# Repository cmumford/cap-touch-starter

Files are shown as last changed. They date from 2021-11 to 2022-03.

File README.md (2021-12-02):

# Introduction

This is a simple hardware/software starter project containing an
MCU (ESP32), and a capacitive touch screen. Nothing fancy, just
something to fork when starting a new project that needs these capabilities.

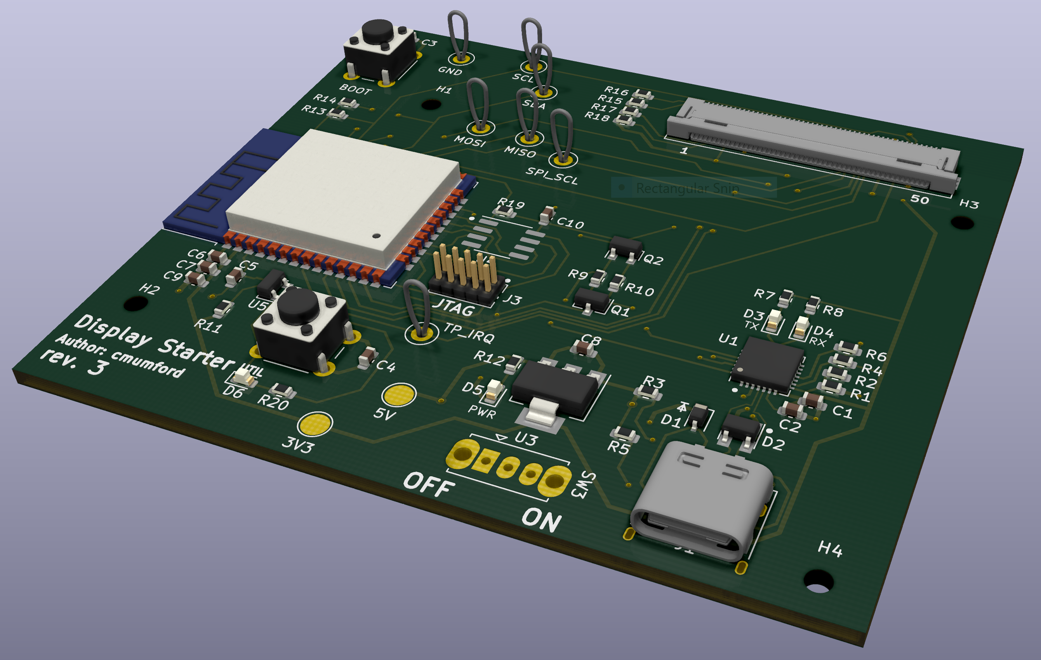
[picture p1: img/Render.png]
Board render


# Main Components

* ESP32-WROVER-E ([Datasheet](https://www.espressif.com/sites/default/files/documentation/esp32-wrover_datasheet_en.pdf))
* [2.8" TFT Display - 240x320 with Capacitive Touchscreen](https://www.adafruit.com/product/2770)
* CP2102N ([Datasheet](https://www.silabs.com/documents/public/data-sheets/cp2102n-datasheet.pdf))
* SPIRAM.
* 10-pin JTAG debug port.

# Board Design

See the [pcb/](pcb/) folder for the schematic and board layout.

# Software

It includes a starter application built with the
[ESP-IDF](https://github.com/espressif/esp-idf) platform framework. The application
[lv_demos](https://github.com/lvgl/lv_demos) which is part of the [LVGL](https://lvgl.io/)
graphics library. This could easily be replaced with a different application

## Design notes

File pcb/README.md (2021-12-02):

# Schematic

[Schematic](Schematic.pdf)

# Layout

[Layout](Layout.pdf)

# BOM

| Quantity | Description | Value | Package |
| --- | --- | --- | --- |
| 3 | Capacitor | 22μF/6.3V | 0603 (1608 Metric) |
| 5 | Capacitor | 0.1μF/50V | 0603 (1608 Metric) |
| 1 | Capacitor | 4.7μF/6.3V | 0603 (1608 Metric) |
| 1 | Diode (Schottsky) | BAT760-7 | SOD-323 |
| 1 | Voltage suppressor | SP0503BAHT | SOT-143 |
| 4 | LED | LED | 0603 (1608 Metric) |
| 1 | USB Type-C Receptacle | [12401548E412A](https://www.digikey.com/en/products/detail/amphenol-icc-commercial-products/12401548E412A/13683580) | |
| 1 | 2.8" LCD w/Capacitive Touch | [DT280QV10-CT](https://www.adafruit.com/product/2770) |  |
| 1 | Flat pack ribbon cable connector | 62684-502100ALF | 50 pin 0.5 mm pitch |
| 2 | NPN Transistor | SS8050-G | SOT-23 |
| 4 | Resistor | 68Ω | 0603 (1608 Metric) |
| 3 | Resistor | 2KΩ | 0603 (1608 Metric) |
| 1 | Resistor | 22K1Ω | 0603 (1608 Metric) |
| 1 | Resistor | 47K5Ω | 0603 (1608 Metric) |
| 4 | Resistor | 10KΩ | 0603 (1608 Metric) |
| 2 | Resistor | 5K1Ω | 0603 (1608 Metric) |
| 2 | Resistor | 2K2Ω | 0603 (1608 Metric) |
| 1 | ESP32-WROVER-E | | |
| 1 | SPIRAM (8 MB) | LY68L6400SLIT | SOP-8 |
| 1 | Voltage Regulator | AMS1117-3.3 | SOT-223 |
| 1 | Voltage Detector | [BD48K33G-TLCT-ND](https://fscdn.rohm.com/en/products/databook/datasheet/ic/power/voltage_detector/bd48xxg-e.pdf) | SOT-23-3 |
| 1 | USB-to-UART bridge controller | CP2102N-A01 | QFN-28 |
| 2 | Tactile pushbutton | | |
| 1 | Slider 1P2T switch | SK-12D07 | |

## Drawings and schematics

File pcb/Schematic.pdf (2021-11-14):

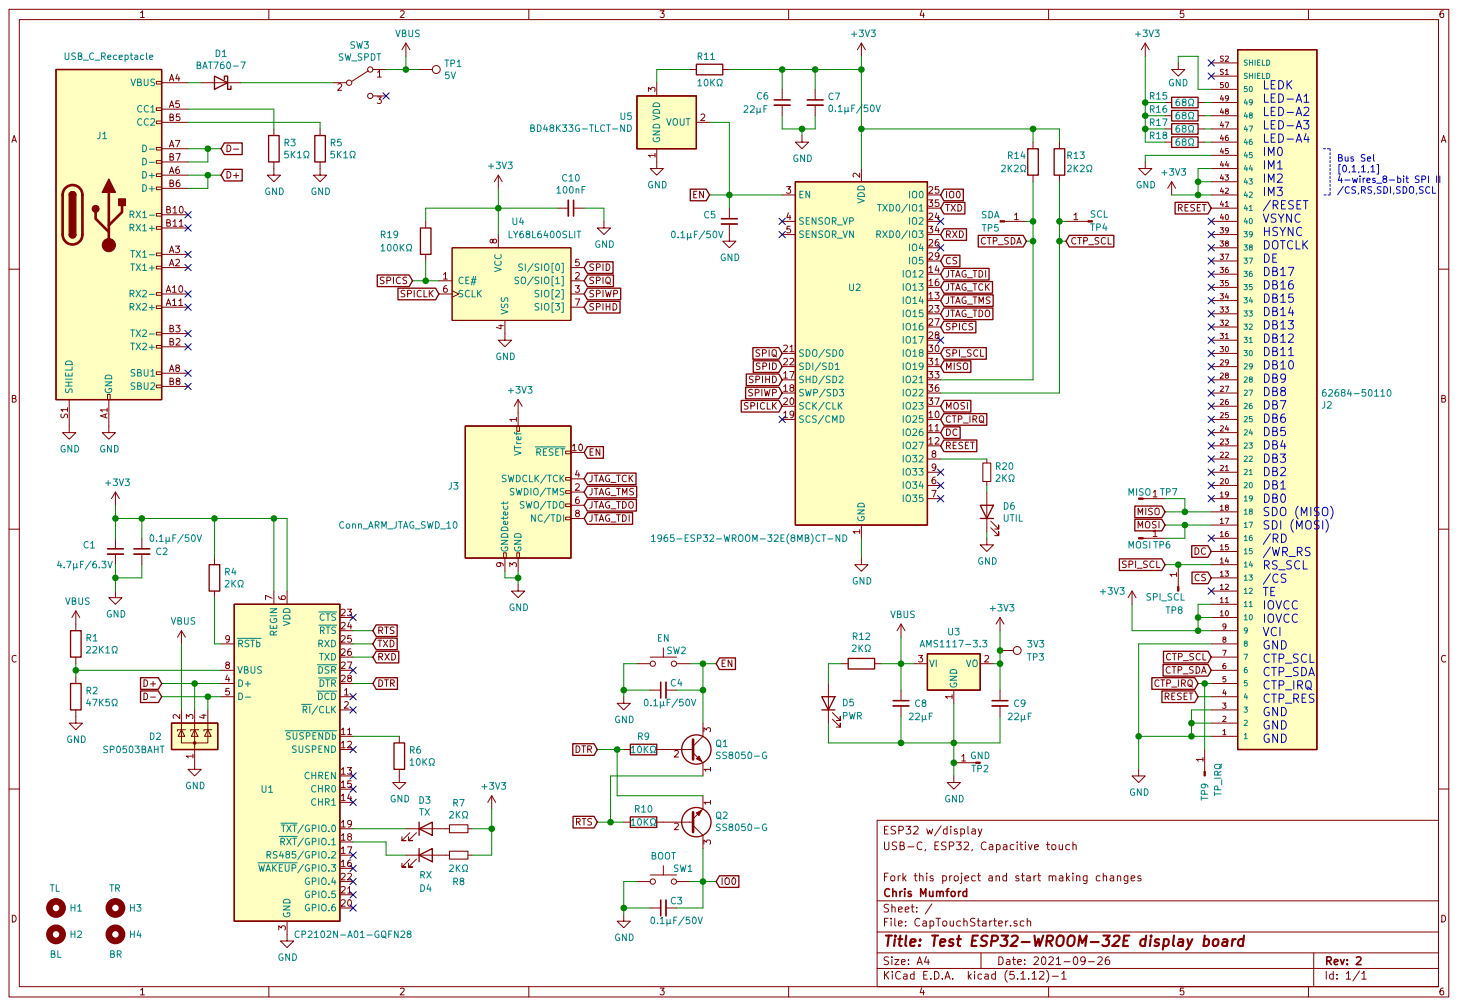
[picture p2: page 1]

3 U5 BD48K33G-TLCT-ND GND GND

Bus Sel [0,1,1,1] 4-wires_8-bit SPI II

2 SCK/CLK 20 SDO/SD0 21 SDI/SD1 22

/CS,RS,SDI,SDO,SCL

4 SI/SIO[0] 5 SCLK 6 SIO[3] 7 VCC

1 TP9 TP_IRQ VTref 1 RESET 10 SWDIO/TMS 2 GND

3 SWDCLK/TCK 4 SWO/TDO 6 NC/TDI 8 GNDDetect 9

7 VBUS 8 RSTb 9 U1 CP2102N-A01-GQFN28 +3V3 H1 TL H3 TR

Fork this project and start making changes
File: CapTouchStarter.sch Sheet: / Chris Mumford

Id: 1/1 Title: Test ESP32-WROOM-32E display board

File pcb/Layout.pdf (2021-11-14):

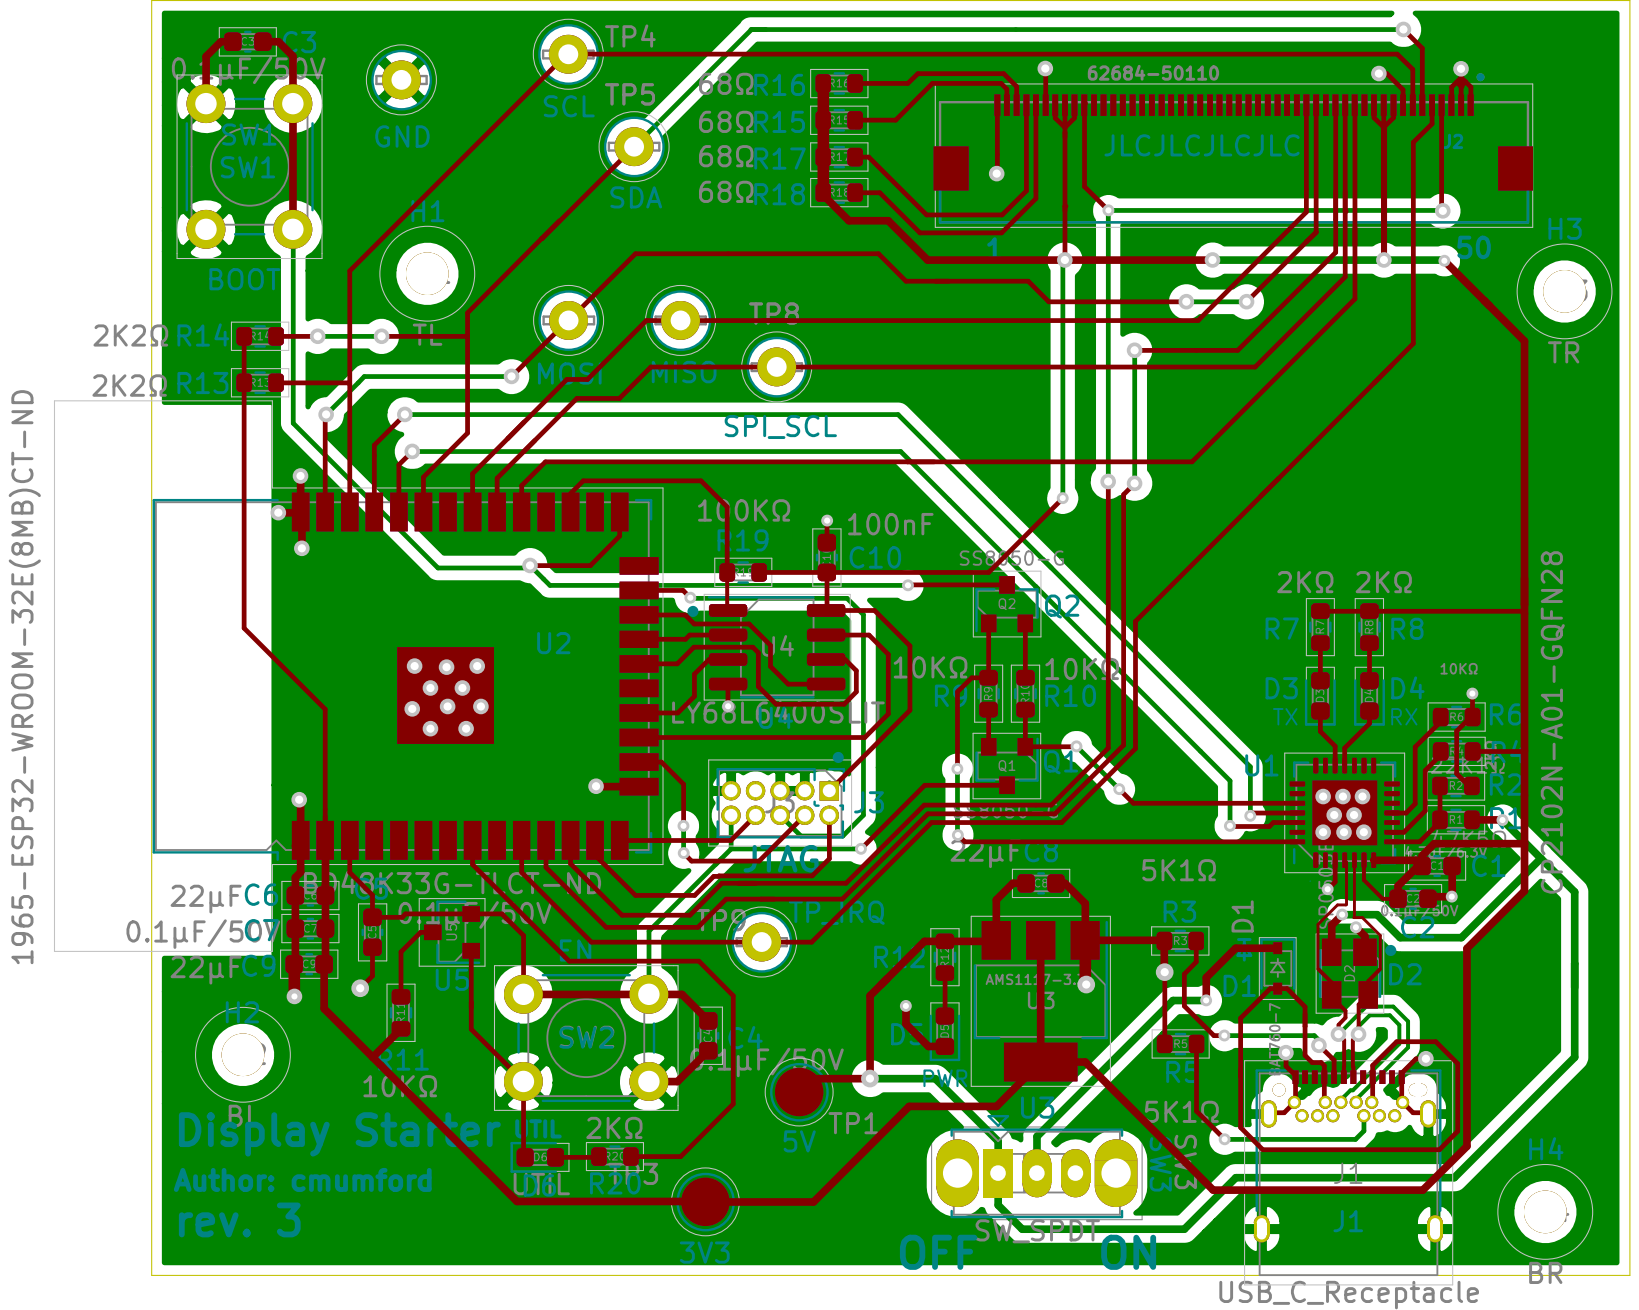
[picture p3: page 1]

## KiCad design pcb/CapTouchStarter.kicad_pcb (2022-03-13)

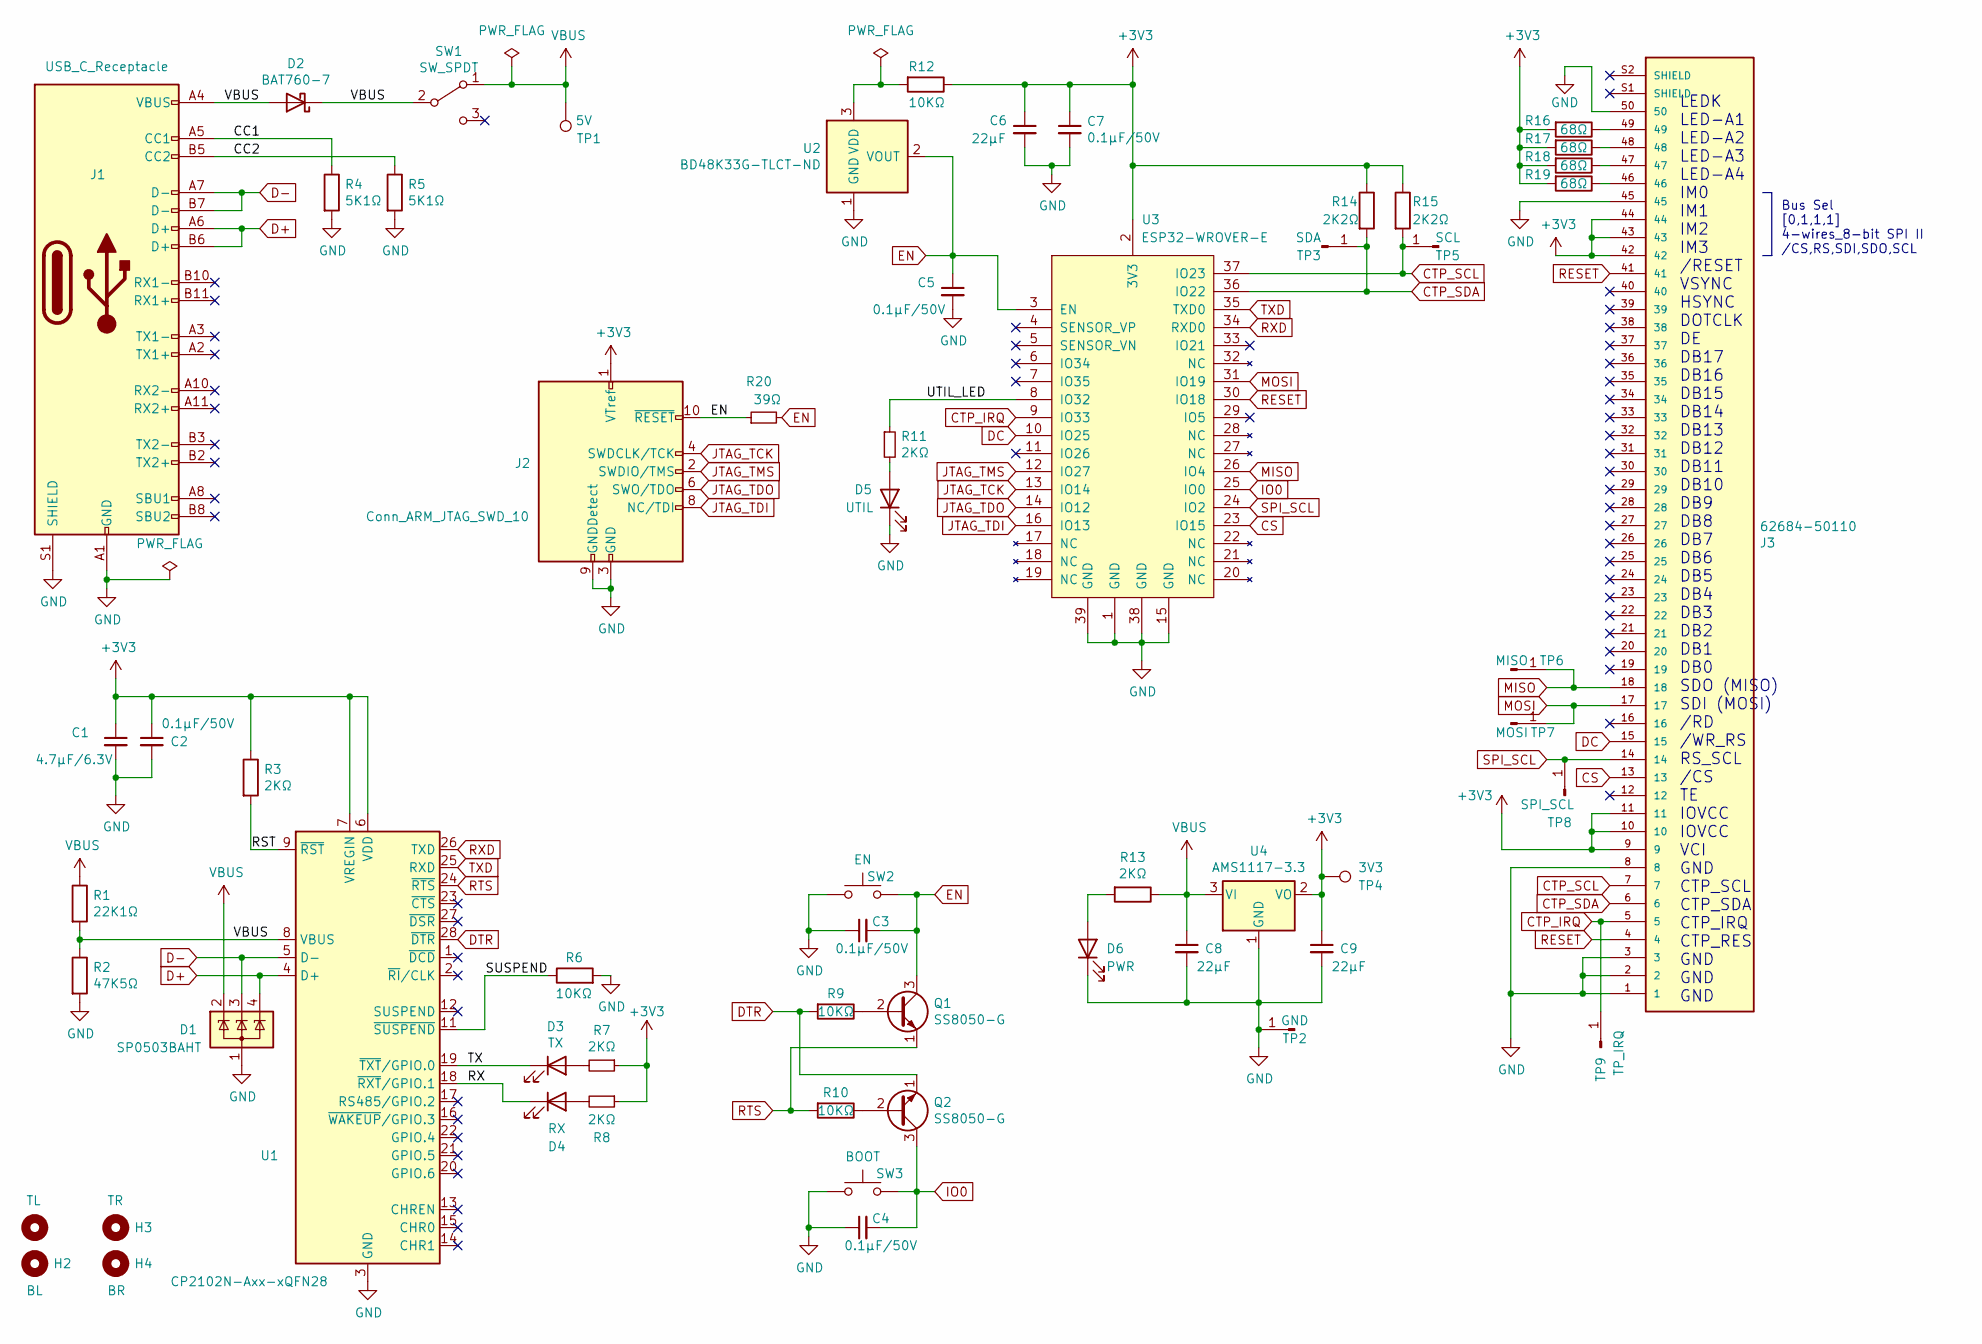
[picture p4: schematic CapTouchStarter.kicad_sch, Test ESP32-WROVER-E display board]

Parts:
C1: 4.7μF/6.3V; C_0603_1608Metric
C2, C3, C4, C5, C7: 0.1μF/50V; C_0603_1608Metric
C6, C8, C9: 22μF; C_0603_1608Metric
D1: SP0503BAHT; SOT-143
D2: BAT760-7; D_SOD-323
D3: TX; LED_0603_1608Metric
D4: RX; LED_0603_1608Metric
D5: UTIL; LED_0603_1608Metric
D6: PWR; LED_0603_1608Metric
H1: TL; MountingHole_2.2mm_M2
H2: BL; MountingHole_2.2mm_M2
H3: TR; MountingHole_2.2mm_M2
H4: BR; MountingHole_2.2mm_M2
J1: USB_C_Receptacle; USB_C_Receptacle_Amphenol_12401548E4-2A
J2: Conn_ARM_JTAG_SWD_10; PinHeader_2x05_P1.27mm_Vertical
J3: 62684-50110
Q1, Q2: SS8050-G; SOT-23
R1: 22K1Ω; R_0603_1608Metric
R2: 47K5Ω; R_0603_1608Metric
R3, R7, R8, R11, R13: 2KΩ; R_0603_1608Metric
R4, R5: 5K1Ω; R_0603_1608Metric
R6, R9, R10, R12: 10KΩ; R_0603_1608Metric
R14, R15: 2K2Ω; R_0603_1608Metric
R16, R17, R18, R19: 68Ω; R_0603_1608Metric
R20: 39Ω; R_0603_1608Metric
SW1: SW_SPDT; SW_Slide_1P2T_CK_OS102011MS2Q
SW2: EN; SW_PUSH_6mm_H5mm
SW3: BOOT; SW_PUSH_6mm_H5mm
TP1: 5V; TestPoint_Pad_D2.5mm
TP2: GND; TestPoint_Loop_D2.50mm_Drill1.0mm
TP3: SDA; TestPoint_Loop_D2.50mm_Drill1.0mm
TP4: 3V3; TestPoint_Pad_D2.5mm
TP5: SCL; TestPoint_Loop_D2.50mm_Drill1.0mm
TP6: MISO; TestPoint_Loop_D2.50mm_Drill1.0mm
TP7: MOSI; TestPoint_Loop_D2.50mm_Drill1.0mm
TP8: SPI_SCL; TestPoint_Loop_D2.50mm_Drill1.0mm
TP9: TP_IRQ; TestPoint_Loop_D2.50mm_Drill1.0mm
U1: CP2102N-Axx-xQFN28; QFN-28-1EP_5x5mm_P0.5mm_EP3.35x3.35mm
U2: BD48K33G-TLCT-ND; SOT-23
U3: ESP32-WROVER-E; ESP32-WROVER-IE
U4: AMS1117-3.3; SOT-223-3_TabPin2

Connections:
+3V3: C1.1, C2.1, C6.1, C7.1, C9.1, J2.1 (VTref), J3.9, J3.10, J3.11, J3.42, J3.43, J3.44, R3.1, R7.1, R8.1, R12.1, R14.1, R15.1, R16.2, R17.2, R18.2, R19.2, TP4.1, U1.6 (VDD), U1.7 (VREGIN), U3.2 (3V3), U4.2 (VO)
/CC1: J1.A5 (CC1), R4.1
/CC2: J1.B5 (CC2), R5.1
/RST: R3.2, U1.9 (~RST)
/RX: D4.1 (K), U1.18 (~RXT/GPIO.1)
/SUSPEND: R6.1, U1.11 (~SUSPEND)
/TX: D3.1 (K), U1.19 (~TXT/GPIO.0)
/UTIL_LED: R11.1, U3.8 (IO32)
CS: J3.13, U3.23 (IO15)
CTP_IRQ: J3.5, TP9.1, U3.9 (IO33)
CTP_SCL: J3.7, R15.2, TP5.1, U3.37 (IO23)
CTP_SDA: J3.6, R14.2, TP3.1, U3.36 (IO22)
D+: D1.4 (K), J1.A6 (D+), J1.B6 (D+), U1.4 (D+)
D-: D1.3 (K), J1.A7 (D-), J1.B7 (D-), U1.5 (D-)
DC: J3.15, U3.10 (IO25)
DTR: Q2.1 (E), R9.2, U1.28 (~DTR)
EN: C3.2, C5.1, J2.10 (~RESET), Q1.3 (C), R20.1, R20.2, SW2.2, U2.2 (VOUT), U3.3 (EN)
GND: C1.2, C2.2, C3.1, C4.1, C5.2, C6.2, C7.2, C8.2, C9.2, D1.1 (A), D5.1 (K), D6.1 (K), J1.A1 (GND), J1.A12 (GND), J1.B1 (GND), J1.B12 (GND), J1.S1 (SHIELD), J2.3 (GND), J2.5 (GND), J2.9 (GNDDetect), J3.1, J3.2, J3.3, J3.8, J3.45, J3.50, R2.2, R4.2, R5.2, R6.2, SW2.1, SW3.1, TP2.1, U1.3 (GND), U1.29 (GND), U2.1 (GND), U3.1 (GND), U3.15 (GND), U3.38 (GND), U3.39 (GND), U4.1 (GND)
IO0: C4.2, Q2.3 (C), SW3.2, U3.25 (IO0)
JTAG_TCK: J2.4 (SWDCLK/TCK), U3.13 (IO14)
JTAG_TDI: J2.8 (NC/TDI), U3.16 (IO13)
JTAG_TDO: J2.6 (SWO/TDO), U3.14 (IO12)
JTAG_TMS: J2.2 (SWDIO/TMS), U3.12 (IO27)
MISO: J3.18, TP6.1, U3.26 (IO4)
MOSI: J3.17, TP7.1, U3.31 (IO19)
unnamed: D3.2 (A), R7.2
unnamed: D4.2 (A), R8.2
unnamed: D5.2 (A), R11.2
unnamed: D6.2 (A), R13.2
unnamed: J3.46, R19.1
unnamed: J3.47, R18.1
unnamed: J3.48, R17.1
unnamed: J3.49, R16.1
unnamed: Q1.2 (B), R9.1
unnamed: Q2.2 (B), R10.1
unnamed: R12.2, U2.3 (VDD)
RESET: J3.4, J3.41, U3.30 (IO18)
RTS: Q1.1 (E), R10.2, U1.24 (~RTS)
RXD: U1.26 (TXD), U3.34 (RXD0)
SPI_SCL: J3.14, TP8.1, U3.24 (IO2)
TXD: U1.25 (RXD), U3.35 (TXD0)
VBUS: C8.1, D1.2 (K), D2.1 (K), D2.2 (A), J1.A4 (VBUS), J1.A9 (VBUS), J1.B4 (VBUS), J1.B9 (VBUS), R1.1, R1.2, R2.1, R13.1, SW1.1 (A), SW1.2 (B), TP1.1, U1.8 (VBUS), U4.3 (VI)

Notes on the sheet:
LEDK LED-A1 LED-A2 LED-A3 LED-A4 IM0 IM1 IM2 IM3 /RESET VSYNC HSYNC DOTCLK DE DB17 DB16 DB15 DB14 DB13 DB12 DB11 DB10 DB9 DB8 DB7 DB6 DB5 DB4 DB3 DB2 DB1 DB0 SDO (MISO) SDI (MOSI) /RD /WR_RS RS_SCL /CS TE IOVCC IOVCC VCI GND CTP_SCL CTP_SDA CTP_IRQ CTP_RES GND GND GND
Bus Sel [0,1,1,1] 4-wires_8-bit SPI II /CS,RS,SDI,SDO,SCL

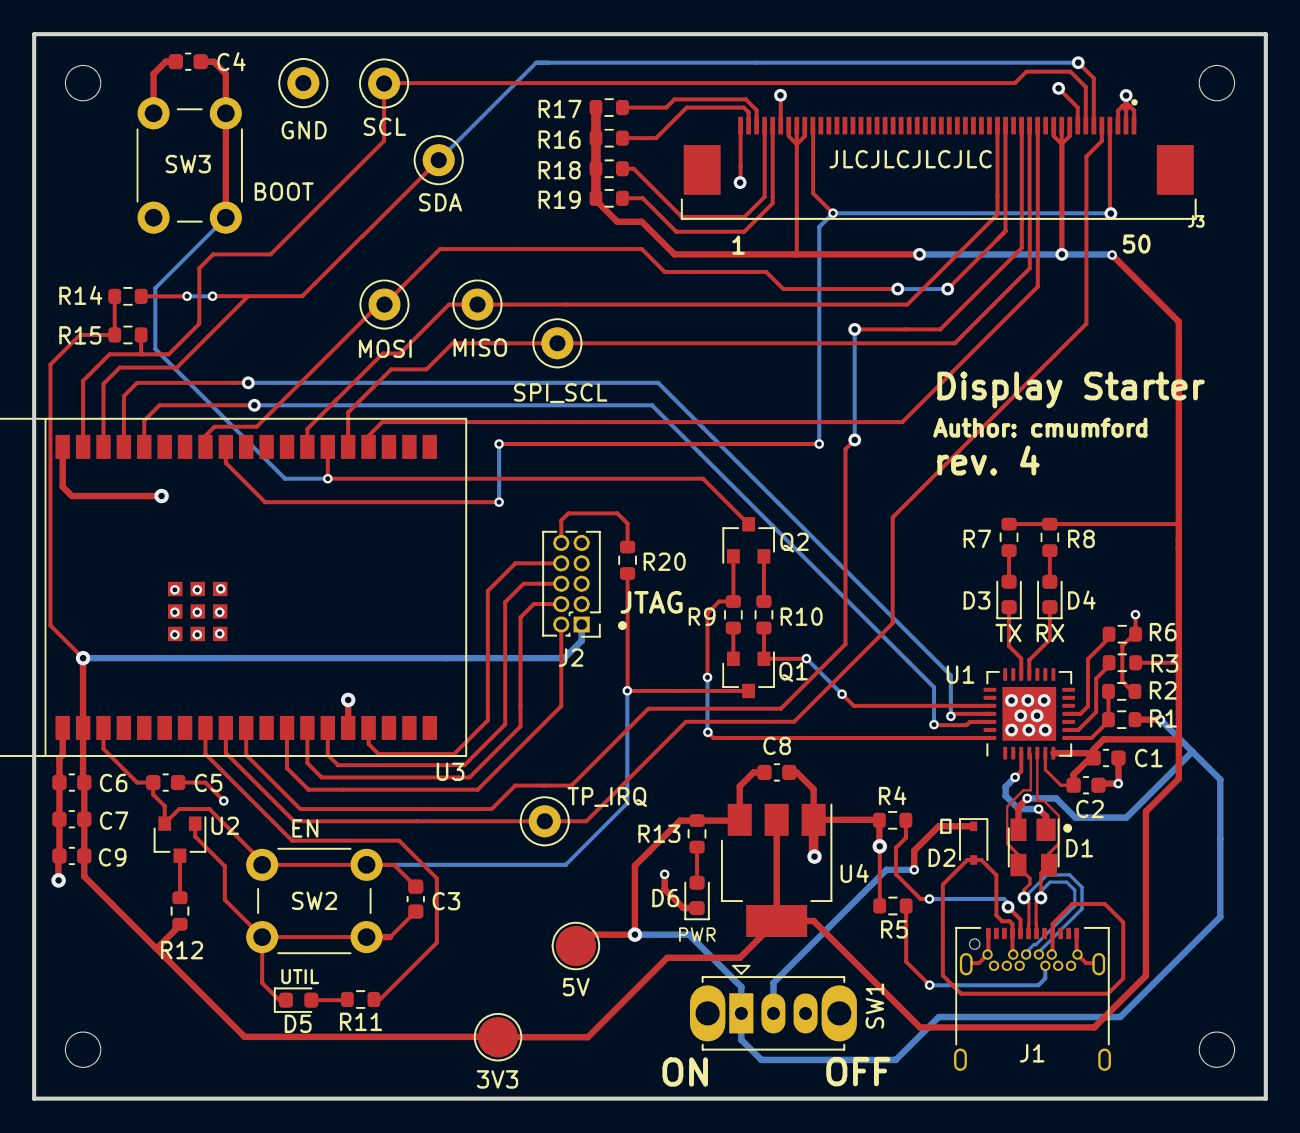
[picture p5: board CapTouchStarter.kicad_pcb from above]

Board: 4 copper layers, 76.7 x 66.3 mm, 60 parts (0 on the bottom side), 42 nets.

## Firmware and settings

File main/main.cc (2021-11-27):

#define LOG_LOCAL_LEVEL ESP_LOG_VERBOSE
#include <driver/include/driver/gpio.h>
#include <esp_log.h>
#include <esp_system.h>
#include <freertos/include/freertos/FreeRTOS.h>
#include <freertos/include/freertos/semphr.h>
#include <freertos/include/freertos/task.h>
#include <sdkconfig.h>
#include <spi_flash/include/esp_spi_flash.h>

#ifdef LV_LVGL_H_INCLUDE_SIMPLE
#include <lvgl.h>
#else
#include <lvgl/lvgl.h>
#endif  // LV_LVGL_H_INCLUDE_SIMPLE

#include <lvgl_helpers.h>

#ifndef CONFIG_LV_TFT_DISPLAY_MONOCHROME
#if defined CONFIG_LV_USE_DEMO_WIDGETS
#include <lv_demos/src/lv_demo_widgets/lv_demo_widgets.h>
#elif defined CONFIG_LV_USE_DEMO_KEYPAD_AND_ENCODER
#include <lv_demos/src/lv_demo_keypad_encoder/lv_demo_keypad_encoder.h>
#elif defined CONFIG_LV_USE_DEMO_BENCHMARK
#include <lv_demos/src/lv_demo_benchmark/lv_demo_benchmark.h>
#elif defined CONFIG_LV_USE_DEMO_STRESS
#include <lv_demos/src/lv_demo_stress/lv_demo_stress.h>
#else
#error "No demo application selected."
#endif
#endif

namespace {

constexpr char TAG[] = "App";
constexpr uint32_t LV_TICK_PERIOD_MS = 1;
SemaphoreHandle_t xGuiSemaphore;

void LogHardwareInfo() {
  esp_chip_info_t chip_info;
  esp_chip_info(&chip_info);
  ESP_LOGI(TAG, "This is %s chip with %d CPU core(s), WiFi%s%s.",
           CONFIG_IDF_TARGET, chip_info.cores,
           (chip_info.features & CHIP_FEATURE_BT) ? "/BT" : "",
           (chip_info.features & CHIP_FEATURE_BLE) ? "/BLE" : "");

  ESP_LOGI(TAG, "Silicon revision %u.", chip_info.revision);

  ESP_LOGI(
      TAG, "%zu MB %s flash", spi_flash_get_chip_size() / (1024 * 1024),
      (chip_info.features & CHIP_FEATURE_EMB_FLASH) ? "embedded" : "external");

  ESP_LOGI(TAG, "Free heap size: %u bytes.", esp_get_free_heap_size());
  ESP_LOGI(TAG, "Free internal heap size: %u bytes.",
           esp_get_free_internal_heap_size());
  ESP_LOGI(TAG, "Minimum free heap size: %u bytes.",
           esp_get_minimum_free_heap_size());

  ESP_LOGI(TAG, "MALLOC_CAP_EXEC: %u bytes.",
           heap_caps_get_total_size(MALLOC_CAP_EXEC));
  ESP_LOGI(TAG, "MALLOC_CAP_32BIT: %u bytes.",
           heap_caps_get_total_size(MALLOC_CAP_32BIT));
  ESP_LOGI(TAG, "MALLOC_CAP_8BIT: %u bytes.",
           heap_caps_get_total_size(MALLOC_CAP_8BIT));
  ESP_LOGI(TAG, "MALLOC_CAP_8BIT: %u bytes.",
           heap_caps_get_total_size(MALLOC_CAP_8BIT));
  ESP_LOGI(TAG, "MALLOC_CAP_DMA: %u bytes.",
           heap_caps_get_total_size(MALLOC_CAP_DMA));
  ESP_LOGI(TAG, "MALLOC_CAP_PID2: %u bytes.",
           heap_caps_get_total_size(MALLOC_CAP_PID2));
  ESP_LOGI(TAG, "MALLOC_CAP_PID3: %u bytes.",
           heap_caps_get_total_size(MALLOC_CAP_PID3));
  ESP_LOGI(TAG, "MALLOC_CAP_PID4: %u bytes.",
           heap_caps_get_total_size(MALLOC_CAP_PID4));
  ESP_LOGI(TAG, "MALLOC_CAP_PID5: %u bytes.",
           heap_caps_get_total_size(MALLOC_CAP_PID5));
  ESP_LOGI(TAG, "MALLOC_CAP_PID6: %u bytes.",
           heap_caps_get_total_size(MALLOC_CAP_PID6));
  ESP_LOGI(TAG, "MALLOC_CAP_PID7: %u bytes.",
           heap_caps_get_total_size(MALLOC_CAP_PID7));
  ESP_LOGI(TAG, "MALLOC_CAP_SPIRAM: %u bytes.",
           heap_caps_get_total_size(MALLOC_CAP_SPIRAM));
  ESP_LOGI(TAG, "MALLOC_CAP_INTERNAL: %u bytes.",
           heap_caps_get_total_size(MALLOC_CAP_INTERNAL));
  ESP_LOGI(TAG, "MALLOC_CAP_DEFAULT: %u bytes.",
           heap_caps_get_total_size(MALLOC_CAP_DEFAULT));
  ESP_LOGI(TAG, "MALLOC_CAP_IRAM_8BIT: %u bytes.",
           heap_caps_get_total_size(MALLOC_CAP_IRAM_8BIT));
}

void lv_tick_task(void* arg) {
  (void)arg;

  lv_tick_inc(LV_TICK_PERIOD_MS);
}

void create_demo_application() {
  /* When using a monochrome display we only show "Hello World" centered on the
   * screen */
#if defined CONFIG_LV_TFT_DISPLAY_MONOCHROME || \
    defined CONFIG_LV_TFT_DISPLAY_CONTROLLER_ST7735S

  /* use a pretty small demo for monochrome displays */
  /* Get the current screen  */
  lv_obj_t* scr = lv_disp_get_scr_act(nullptr);

  /*Create a Label on the currently active screen*/
  lv_obj_t* label1 = lv_label_create(scr, nullptr);

  /*Modify the Label's text*/
  lv_label_set_text(label1, "Hello\nworld");

  /* Align the Label to the center
   * nullptr means align on parent (which is the screen now)
   * 0, 0 at the end means an x, y offset after alignment*/
  lv_obj_align(label1, nullptr, LV_ALIGN_CENTER, 0, 0);
#else
  /* Otherwise we show the selected demo */

#if defined CONFIG_LV_USE_DEMO_WIDGETS
  lv_demo_widgets();
#elif defined CONFIG_LV_USE_DEMO_KEYPAD_AND_ENCODER
  lv_demo_keypad_encoder();
#elif defined CONFIG_LV_USE_DEMO_BENCHMARK
  lv_demo_benchmark();
#elif defined CONFIG_LV_USE_DEMO_STRESS
  lv_demo_stress();
#else
#error "No demo application selected."
#endif
#endif
}

void guiTask(void* pvParameter) {
  (void)pvParameter;
  xGuiSemaphore = xSemaphoreCreateMutex();

  lv_init();

  /* Initialize SPI or I2C bus used by the drivers */
  lvgl_driver_init();

  lv_color_t* buf1 = static_cast<lv_color_t*>(
      heap_caps_malloc(DISP_BUF_SIZE * sizeof(lv_color_t), MALLOC_CAP_DMA));
  assert(buf1 != nullptr);

  /* Use double buffered when not working with monochrome displays */
#ifndef CONFIG_LV_TFT_DISPLAY_MONOCHROME
  lv_color_t* buf2 = static_cast<lv_color_t*>(
      heap_caps_malloc(DISP_BUF_SIZE * sizeof(lv_color_t), MALLOC_CAP_DMA));
  assert(buf2 != nullptr);
#else
  static lv_color_t* buf2 = nullptr;
#endif

  static lv_disp_draw_buf_t disp_buf;

  uint32_t size_in_px = DISP_BUF_SIZE;

#if defined CONFIG_LV_TFT_DISPLAY_CONTROLLER_IL3820 ||   \
    defined CONFIG_LV_TFT_DISPLAY_CONTROLLER_JD79653A || \
    defined CONFIG_LV_TFT_DISPLAY_CONTROLLER_UC8151D ||  \
    defined CONFIG_LV_TFT_DISPLAY_CONTROLLER_SSD1306

  /* Actual size in pixels, not bytes. */
  size_in_px *= 8;
#endif

  /* Initialize the working buffer depending on the selected display.
   * NOTE: buf2 == nullptr when using monochrome displays. */
  lv_disp_draw_buf_init(&disp_buf, buf1, buf2, size_in_px);

  lv_disp_drv_t disp_drv;
  lv_disp_drv_init(&disp_drv);
  disp_drv.flush_cb = disp_driver_flush;

  /* When using a monochrome display we need to register the callbacks:
   * - rounder_cb
   * - set_px_cb */
#ifdef CONFIG_LV_TFT_DISPLAY_MONOCHROME
  disp_drv.rounder_cb = disp_driver_rounder;
  disp_drv.set_px_cb = disp_driver_set_px;
#endif

  disp_drv.draw_buf = &disp_buf;
  lv_disp_drv_register(&disp_drv);

  /* Register an input device when enabled on the menuconfig */
#if CONFIG_LV_TOUCH_CONTROLLER != TOUCH_CONTROLLER_NONE
  lv_indev_drv_t indev_drv;
  lv_indev_drv_init(&indev_drv);
  indev_drv.read_cb = touch_driver_read;
  indev_drv.type = LV_INDEV_TYPE_POINTER;
  lv_indev_drv_register(&indev_drv);
#endif

  /* Create and start a periodic timer interrupt to call lv_tick_inc */
  const esp_timer_create_args_t periodic_timer_args = {
      .callback = &lv_tick_task,
      .arg = nullptr,
      .dispatch_method = ESP_TIMER_TASK,
      .name = "periodic_gui",
      .skip_unhandled_events = false,
  };
  esp_timer_handle_t periodic_timer;
  ESP_ERROR_CHECK(esp_timer_create(&periodic_timer_args, &periodic_timer));
  ESP_ERROR_CHECK(
      esp_timer_start_periodic(periodic_timer, LV_TICK_PERIOD_MS * 1000));

  create_demo_application();

  while (true) {
    /* Delay 1 tick (assumes FreeRTOS tick is 10ms */
    vTaskDelay(pdMS_TO_TICKS(10));

    if (pdTRUE == xSemaphoreTake(xGuiSemaphore, portMAX_DELAY)) {
      lv_task_handler();
      xSemaphoreGive(xGuiSemaphore);
    }
  }

  /* A task should NEVER return */
  free(buf1);
#ifndef CONFIG_LV_TFT_DISPLAY_MONOCHROME
  free(buf2);
#endif
  vTaskDelete(nullptr);
}

void ResetTouchPanel() {
  ESP_ERROR_CHECK(gpio_set_level(GPIO_NUM_4, 0));
  vTaskDelay(pdMS_TO_TICKS(50));
  ESP_ERROR_CHECK(gpio_set_level(GPIO_NUM_4, 1));
}

void LEDTaskFunc(void* arg) {
  uint32_t led_level = 1;
  ESP_LOGI(TAG, "In LED blinking task.");
  while (true) {
    gpio_set_level(GPIO_NUM_32, led_level);
    vTaskDelay(pdMS_TO_TICKS(1000));
    led_level = 1 - led_level;
  }
}

esp_err_t CreateLEDBlinkTask() {
  constexpr uint16_t kStackDepthWords = 2048;
  return xTaskCreate(LEDTaskFunc, TAG, kStackDepthWords, nullptr,
                     tskIDLE_PRIORITY + 1, nullptr) == pdPASS
             ? ESP_OK
             : ESP_FAIL;
}

}  // namespace

extern "C" void app_main() {
  ESP_LOGI(TAG, "CapTouchStarter app!");
  LogHardwareInfo();

  constexpr gpio_config_t config = {
      .pin_bit_mask = ((1ULL << GPIO_NUM_4) | (1ULL << GPIO_NUM_32)),
      .mode = GPIO_MODE_OUTPUT,
      .pull_up_en = GPIO_PULLUP_DISABLE,
      .pull_down_en = GPIO_PULLDOWN_DISABLE,
      .intr_type = GPIO_INTR_DISABLE,
  };
  ESP_ERROR_CHECK(gpio_config(&config));

  ResetTouchPanel();

  ESP_ERROR_CHECK(CreateLEDBlinkTask());

  xTaskCreatePinnedToCore(guiTask, "gui", 4096 * 2, nullptr, 0, nullptr, 1);
}

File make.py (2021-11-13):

#!/usr/bin/env python3

import errno
import glob
import os
import platform
import serial.tools.list_ports
import subprocess
import sys
from pprint import pprint
from enum import Enum

class ConsoleTarget(Enum):
    UART = 1
    CDC = 2
    CUSTOM = 3
    NONE = 4

class SdkConfigManager(object):
    @staticmethod
    def GetConsoleTarget(sdkconfig) -> int:
        if 'CONFIG_ESP_CONSOLE_UART' in sdkconfig and \
                sdkconfig['CONFIG_ESP_CONSOLE_UART'] == 'y':
            return ConsoleTarget.UART
        if 'CONFIG_ESP_CONSOLE_CDC' in sdkconfig and \
                sdkconfig['CONFIG_ESP_CONSOLE_CDC'] == 'y':
            return ConsoleTarget.CDC
        if 'CONFIG_ESP_CONSOLE_CUSTOM' in sdkconfig and \
                sdkconfig['CONFIG_ESP_CONSOLE_CUSTOM'] == 'y':
            return ConsoleTarget.CUSTOM
        return ConsoleTarget.NONE

    @staticmethod
    def Load() -> dict:
        values = dict()
        try:
            with open('sdkconfig', 'r') as f:
                for line in f.readlines():
                    line = line.strip()
                    if len(line) < 1:
                        continue
                    if line[0] == '#':
                        continue
                    items = line.split('=')
                    if len(items) != 2:
                        print(line)
                    if items[0] in values:
                        print('Already have: ' + line)
                    values[items[0]] = items[1]
        except FileNotFoundError:
            pass
        return values


class PortEnumerator(object):
    def __init__(self):
        pass

    def GetSerialPorts(self) -> list:
        pass

    def GetModemPorts(self) -> list:
        pass

class WindowsPortEnumerator(PortEnumerator):
    def GetSerialPorts(self) -> list:
        ports = []
        for port in serial.tools.list_ports.comports():
            ports.append(port.device)
        return ports

    def GetModemPorts(self) -> list:
        return self.GetSerialPorts()

class MacPortEnumerator(PortEnumerator):
    ignored = ('/dev/cu.Bluetooth-Incoming-Port')

    @staticmethod
    def __GetSerialWildcard() -> str:
        return '/dev/cu.usbserial-*'

    @staticmethod
    def __GetModemWildcard() -> str:
        return '/dev/cu.usbmodem*'

    @staticmethod
    def __GetMatchingPorts(wildcard) -> list:
        ports = []
        for file in glob.glob(wildcard, recursive=False):
            if file in MacPortEnumerator.ignored:
                continue
            ports.append(file)
        return ports

    def GetSerialPorts(self) -> list:
        return MacPortEnumerator.__GetMatchingPorts(
                MacPortEnumerator.__GetSerialWildcard())

    def GetModemPorts(self) -> list:
        return MacPortEnumerator.__GetMatchingPorts(
                MacPortEnumerator.__GetModemWildcard())

class PortManager(object):
    def __init__(self, sdkconfig, port_enumerator):
        self.__sdkconfig = sdkconfig
        self.__console_target = SdkConfigManager.GetConsoleTarget(sdkconfig)
        self.__port_enumerator = port_enumerator

    def GetFlashPort(self) -> str:
        ports = self.__port_enumerator.GetModemPorts()
        if ports:
            return ports[0]
        ports = self.__port_enumerator.GetSerialPorts()
        return ports[0] if ports else None

    def GetMonitorPort(self) -> str:
        if self.__console_target == ConsoleTarget.UART:
            ports = self.__port_enumerator.GetSerialPorts()
        else:
            ports = self.__port_enumerator.GetModemPorts()
        return ports[0] if ports else None

    def PrintPorts(self, fd=sys.stdout):
        print('Serial ports: %s' % self.__port_enumerator.GetSerialPorts(), file=fd)
        print('Modem ports: %s' % self.__port_enumerator.GetModemPorts(), file=fd)
        print('Flash port: %s' % self.GetFlashPort(), file=fd)
        print('Monitor port: %s' % self.GetMonitorPort(), file=fd)


def TargetNeedsMonitorPort(target):
    return target in ('monitor')


def TargetNeedsFlashPort(target):
    return target in ('flash', 'app-flash', 'flash-erase', 'manual-flash')


def MakeTargets(targets, port_manager):
    flash_port = port_manager.GetFlashPort()
    monitor_port = port_manager.GetMonitorPort()
    for target in targets:
        if TargetNeedsMonitorPort(target) and not monitor_port:
            print("Target \"%s\" needs a monitor port, but can't find one." %
                  target,
                  file=sys.stderr)
            port_manager.PrintPorts(sys.stderr)
            sys.exit(errno.ENODEV)
        if TargetNeedsFlashPort(target) and not flash_port:
            print("Target \"%s\" needs a flash port, but can't find one." %
                  target,
                  file=sys.stderr)
            port_manager.PrintPorts(sys.stderr)
            sys.exit(errno.ENODEV)
    if flash_port:
        os.environ["FLASH_PORT"] = flash_port
    if monitor_port:
        os.environ["MONITOR_PORT"] = monitor_port
    cmd = ['make', '--file=Makefile-build']
    cmd.extend(targets)
    subprocess.check_call(cmd)


if 'IDF_PATH' not in os.environ:
    print('ESP-IDF environment not sourced. Run:', file=sys.stderr)
    print(file=sys.stderr)
    print('. $HOME/esp/esp-idf/export.sh', file=sys.stderr)
    print(file=sys.stderr)
    sys.exit(1)

if platform.system() == 'Windows':
    port_enumerator = WindowsPortEnumerator()
else:
    port_enumerator = MacPortEnumerator()

port_manager = PortManager(SdkConfigManager.Load(), port_enumerator)

targets = sys.argv[1:]
MakeTargets(targets, port_manager)

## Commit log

2021-11-13 Add footprint+symbol for 62684-50110.
    This is a 50-pin 0.5mm pitch flat panel connector (FPC).
    https://www.adafruit.com/product/1492
    [CapTouchProto.kicad_pcb, CapTouchProto.sch]
2021-11-13 Added flat panel connector to schematic.
    [CapTouchProto.sch]
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2021-11-13 Lots of connecting up stuff.
    [CapTouchProto.kicad_pcb, CapTouchProto.sch]
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2021-11-13 Layout of usb-c power.
    [CapTouchProto.kicad_pcb]
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2021-11-13 USB-C 5.1K resistor layout.
    [CapTouchProto.kicad_pcb, CapTouchProto.sch]
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2021-11-13 Specified 6mmx5mm tactile buttons.
    [CapTouchProto.kicad_pcb, CapTouchProto.sch]
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2021-11-13 Settings for creating Gerber files.
    [CapTouchProto.kicad_pcb]
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2021-11-13 Added dot for CP2102N pin 1.
    [CapTouchProto.kicad_pcb]
2021-11-13 Moved some passives on layout for better labeling.
    [CapTouchProto.kicad_pcb, CapTouchProto.sch]
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2021-11-13 Fix switch labeling, more cleanup.
    [CapTouchProto.kicad_pcb, CapTouchProto.sch]
2021-11-13 CP2102 VCC/REGIN pins to 3.3V instead of VBUS.
    Oops!
    [CapTouchProto.kicad_pcb, CapTouchProto.sch]
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2021-11-13 Unified value names.
    Renamed component values so that the coalesce into groups
    when creating a BOM.
    [CapTouchProto.sch]
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2021-11-13 Renamed KiCad project files to match repo name.
    [CapTouchStarter.kicad_pcb, CapTouchStarter.sch]
2021-11-13 Using 3V3 for display VCC.
    [CapTouchStarter.kicad_pcb, CapTouchStarter.sch]
2021-11-13 Switched display mode to 4-wires_8-bit SPI.
    Set the interface mode pins (IM0..IM3) to [0, 1, 1, 0].
    [CapTouchStarter.kicad_pcb, CapTouchStarter.sch]
2021-11-13 Connected display backlight cathode (LEDK) to GND.
    [CapTouchStarter.kicad_pcb, CapTouchStarter.sch]
2021-11-13 Added script to delete files.
    Simplify the cleaning process with a script to delete files/dirs.
    Adding this because PowerShell's Remove-Item command doesn't take
    multiple args, and also returns a non-zero error code for nonexistent
    items - even with the `-ErrorAction Ignore` argument.
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2021-11-13 Back to 4-wire SPI II bus.
    Bus Sel
    [0,1,1,1]
    4-wires_8-bit SPI II
    /CS,RS,SDI,SDO,SCL
    [CapTouchStarter.kicad_pcb, CapTouchStarter.sch]
2021-11-13 Corrected LCD pin order.
    The 50-pin flat pack ribbon cable has reversed pin ordering.
    [CapTouchStarter.kicad_pcb, CapTouchStarter.sch]
2021-11-13 Removed 0Ω TX/RX resistors.
    Also minor routing cleanup.
    [CapTouchStarter.kicad_pcb, CapTouchStarter.sch]
2021-11-13 Added TX/RX LED's.
    Also, layout cleanup.
    [CapTouchStarter.kicad_pcb, CapTouchStarter.sch]
2021-11-13 Update layout/schematic PDFs.
    And update board design version to 2.
    [CapTouchStarter.sch]
2021-11-13 Added display silkscreen pin numbers.
    [CapTouchStarter.kicad_pcb]
2021-11-13 Add SPI test points.
    [CapTouchStarter.kicad_pcb, CapTouchStarter.sch]
2021-11-13 Use global labels to cleanup schematic.
    [CapTouchStarter.kicad_pcb, CapTouchStarter.sch]
2021-11-13 Move GND test pad below voltage regulator in schematic.
    No changes to layout.
    [CapTouchStarter.kicad_pcb, CapTouchStarter.sch]
2021-11-13 Combine DTR/RTS EN/IO0 sections.
    [CapTouchStarter.kicad_pcb, CapTouchStarter.sch]
2021-11-13 Add JTAG debugger connector.
    [CapTouchStarter.kicad_pcb, CapTouchStarter.sch]
2021-11-13 Add pin 1 identifiers.
    Also move 3V3 and 5V test pads (make inline).
    [CapTouchStarter.kicad_pcb]
2021-11-13 Import JLCPCB design rules for 1-2 layer boards.
    Source: https://github.com/sethhillbrand/kicad_templates
    [CapTouchStarter.kicad_pcb]
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2021-11-13 Added PSRAM to circuit.
    https://pcbartists.com/design/embedded/esp32-psram-schematic-notes/
    [CapTouchStarter.sch]
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2021-11-13 Moved voltage regulator in layout.
    [CapTouchStarter.kicad_pcb]
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2021-11-13 pcb: Very minor alignments and clenup.
    [CapTouchStarter.kicad_pcb]
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2021-11-13 Added power switch.
    A horizontal slider switch to enable/disable entire device.
    [CapTouchStarter.kicad_pcb, CapTouchStarter.sch]
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2021-11-13 Using FPC STP file.
    [CapTouchStarter.kicad_pcb, CapTouchStarter.sch]
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2021-11-13 Added mounting holes for standoffs.
    Not pretty, but should work.
    [CapTouchStarter.kicad_pcb, CapTouchStarter.sch]
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2021-11-13 Add a voltage detector.
    Add a BD48K33G-TLCT-ND voltage detector.
    [CapTouchStarter.kicad_pcb, CapTouchStarter.sch]
2021-11-13 Fixed ground via overlapping display anchor pad.
    [CapTouchStarter.kicad_pcb]
2021-11-13 Added antenna keep-out zone for copper fill.
    [CapTouchStarter.kicad_pcb]
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2021-11-13 Removed 0Ω resistors from the BOM.
    These were in rev 1 for testing, but no longer used.
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2021-11-14 Added utility LED connected to IO32.
    [CapTouchStarter.kicad_pcb, CapTouchStarter.sch]
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2021-11-14 Figured out capacitive touch issue.
    Corrent board has a solder bridge that shorts SCL to GND. Hopefully
    that is the only problem.
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2021-11-14 Add missing trace for UTIL LED.
    [CapTouchStarter.kicad_pcb]
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2021-11-26 Changed schematic version to 3.
    [CapTouchStarter.sch]
2021-11-26 Add more space between GND and 3v3 on display connector.
    [CapTouchStarter.kicad_pcb]
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2021-11-26 Added USB C connector 3d model.
    Not the correct model - just a placeholder.
    [CapTouchStarter.kicad_pcb]
2021-11-26 pcb: swapped on/off label positions.
    [CapTouchStarter.kicad_pcb]
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2021-11-26 Switched JTAG footprint to 3220-10-0100-00.
    [CapTouchStarter.kicad_pcb, CapTouchStarter.sch]
2021-11-26 pcb: Changed revision to 4.
    [CapTouchStarter.kicad_pcb, CapTouchStarter.sch]
2021-11-26 pcb: Added layout metadata.
    [CapTouchStarter.kicad_pcb]
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2021-12-02 Change layout for ESP32-WROVER-E.
    [CapTouchStarter.kicad_pcb, CapTouchStarter.sch]
2021-12-02 Reverted JTAG back to PinHeader_2x05_P1.27mm_Vertical
    The 3220-10-0100-00 footprint didn't pass the DRT checks
    for JLCPCB's manufacturering specifications.
    This is a revert of e6e3ab1.
    [CapTouchStarter.kicad_pcb, CapTouchStarter.sch]
2021-12-02 Switched to ESP32-WROVER-E footprint w/courtyard.
    [CapTouchStarter.kicad_pcb]
2021-12-02 Added NC to unused ESP32 pins.
    [CapTouchStarter.sch]
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2022-01-23 More DRC fixes.
    [CapTouchStarter.kicad_pcb]
2022-01-23 Switched to KiCAD 6 CP2102N symbol.
    It looks like the v5 CP2102N-A01-GQFN28 symbol was renamed
    to CP2102N-Axx-xQFN28 in v6.
    [CapTouchStarter.kicad_pcb, CapTouchStarter.kicad_sch]
2022-01-23 Cleanup and IO0 route fix.
    [CapTouchStarter.kicad_pcb, CapTouchStarter.kicad_sch]
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2022-01-25 Add JTAG RESET series resistor.
    Eliminate the following ERC warning:
    "Pins of type Output and Open collector are connector".
    Discussion at
    https://www.reddit.com/r/AskElectronics/comments/754epz/series_resistors_on_jtag_lines/
    Also, fixed D+/D- ESD pad assignments and a few silkscreen inside
    cut boundaries ERC warnings.
    [CapTouchStarter.kicad_pcb, CapTouchStarter.kicad_sch]
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2022-01-30 Specifying USB-C STP file.
    The built-in Connector_USB:USB_C_Receptacle_Amphenol_12401548E4-2A
    footprint's STP file produces this error:
    File not found
    ${KICAD6_3DMODEL_DIR}/Connector_USB.3dshapes/USB_C_Receptacle_Amphenol_12401548E4-2A.wrl
    Using the STP file from
    https://www.amphenol-icc.com/usb3-2-gen2-12401548e412a.html
    [CapTouchStarter.kicad_pcb]
2022-01-31 Updated footprint for "50-pin 0.5mm pitch top-contact FPC SMT Connector"
    [CapTouchStarter.kicad_pcb]
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
